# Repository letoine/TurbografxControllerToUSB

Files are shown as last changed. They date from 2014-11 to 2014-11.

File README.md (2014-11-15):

TurbografxControllerToUSB
=========================

Simple adapter that transforms a Turbografx controller into a USB controller.

Turbografx controller pinout
============================

pin |      name       | comment
----|-----------------|---------
 1  | +5V             |
 2  | Data0           |
 3  | Data1           |
 4  | Data2           |
 5  | Data3           |
 6  | Data select     |
 7  | ~Output Enable~ | Also used as clock for auto-fire
 8  | GND             |

Data select |   Data0    |   Data1   |     Data2     |    Data3
------------|------------|-----------|---------------|------------
 High       | Up         | Right     | Down          | Left
 Low        | I button   | II button | Select button | Run button
 High       | 0          | 0         | 0             | 0
 Low        | III button | IV button | V button      | VI button

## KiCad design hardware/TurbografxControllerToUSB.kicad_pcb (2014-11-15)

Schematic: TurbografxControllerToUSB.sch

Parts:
C1, C2: 22p
C3, C5: 100nf
C4: 1uf
CON1: AVR-ISP6; AVR-ISP-6
J1: USB
J2: DIN8
J3: MINIDIN8
R1, R2: 22ohms
R3: 10K
U1: ATMEGA32U2-AU
X1: 16Mhz

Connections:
DATA0: J2.2, J3.2, U1.9
DATA1: J2.3, J3.3, U1.7
DATA2: J2.4, J3.4, U1.10
DATA3: J2.5, J3.5, U1.8
DATA_SELECT: J2.6, J3.6, U1.11
GND: C1.2, C2.2, C3.1, C4.1, C5.2, CON1.6 (GND), J1.4 (GND), J1.5 (Shield_1), J1.6 (Shield_2), J2.8, J2.9 (shield), J3.8, J3.9 (shield), U1.3, U1.28
MISO: CON1.1 (MISO), U1.17
MOSI: CON1.4 (MOSI), U1.16
unnamed: R1.2, U1.30
unnamed: J1.2 (D-), R1.1
unnamed: J1.3 (D+), R2.1
unnamed: C4.2, U1.27
unnamed: R2.2, U1.29
unnamed: C2.1, U1.2, X1.2
unnamed: C1.1, U1.1, X1.1
RESET: C5.1, CON1.5 (RST), R3.2, U1.24
SCK: CON1.3 (SCK), U1.15
VCC: C3.2, CON1.2 (VCC), J1.1 (Vbus), J2.1, J3.1, R3.1, U1.4, U1.31, U1.32
~OE~: J2.7, J3.7, U1.6

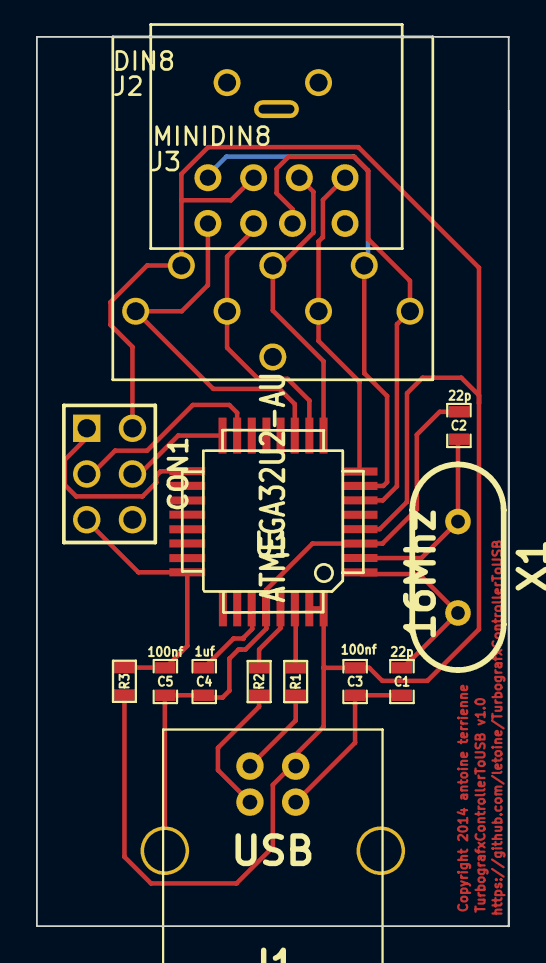
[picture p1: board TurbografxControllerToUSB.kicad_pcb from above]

Board: 2 copper layers, 26.2 x 49.4 mm, 14 parts (0 on the bottom side), 19 nets.

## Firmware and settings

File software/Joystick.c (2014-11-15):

#include "Joystick.h"

static uint8_t PrevJoystickHIDReportBuffer[sizeof(USB_JoystickReport_Data_t)];

/* TODO: Need to check at which frequency the console is toggling
         the chip_enable pin to reproduce the same autofire frequency.
static bool JoystickNeedsReset;

ISR(TIMER1_COMPA_vect) {
  JoystickNeedsReset = true;
}

void init_reset_timer() {
  JoystickNeedsReset = false;
  TCCR1A = 0;
  TCCR1B = _BV(WGM12);
  TCCR1C = 0;
  TCNT1 = 0;
  OCR1A = F_CPU/60;
  TIMSK1 |= _BV(OCIE1A); // enable timer interruption
  TCCR1B |= _BV(CS10); // enable timer clock
}
*/

USB_ClassInfo_HID_Device_t Joystick_HID_Interface = {
  .Config = {
    .InterfaceNumber = INTERFACE_ID_Joystick,
    .ReportINEndpoint = {
      .Address              = JOYSTICK_EPADDR,
      .Size                 = JOYSTICK_EPSIZE,
      .Banks                = 1,
    },
    .PrevReportINBuffer           = PrevJoystickHIDReportBuffer,
    .PrevReportINBufferSize       = sizeof(PrevJoystickHIDReportBuffer),
  },
};

#define IO_PIN	PIND
#define IO_PORT	PORTD
#define IO_DDR	DDRD

#define OUTPUT_ENABLE_PIN	0

#define DATA1_PIN		1
#define DATA3_PIN		2
#define DATA0_PIN		3
#define DATA2_PIN		4

#define SELECT_PIN		5

#define INPUT_PINS_MASK	(_BV(DATA0_PIN)|_BV(DATA1_PIN)|_BV(DATA2_PIN)|_BV(DATA3_PIN))
#define OUTPUT_PINS_MASK	(_BV(OUTPUT_ENABLE_PIN)|_BV(SELECT_PIN))

#define enable_controller_chip()	(IO_PORT &= ~(_BV(OUTPUT_ENABLE_PIN)))
#define disable_controller_chip()	(IO_PORT |= _BV(OUTPUT_ENABLE_PIN))
#define set_select_to_high()		(IO_PORT |= _BV(SELECT_PIN))
#define set_select_to_low()		(IO_PORT &= ~(_BV(SELECT_PIN)))

typedef union {
  uint8_t raw;
  struct {
    unsigned int pad1:1;
    
    unsigned int right:1;
    unsigned int left:1;
    unsigned int up:1;
    unsigned int down:1;
    
    unsigned int pad2:3;
  } directions;
  struct {
    unsigned int pad1:1;
    
    unsigned int II_btn:1;
    unsigned int run:1;
    unsigned int I_btn:1;
    unsigned int select:1;
    
    unsigned int pad2:3;
  } btn1;
  struct {
    unsigned int pad1:1;
    
    unsigned int IV_btn:1;
    unsigned int VI_btn:1;
    unsigned int III_btn:1;
    unsigned int V_btn:1;
    
    unsigned int pad2:3;
  } btn2;
} input_defs;

int main(void) {
  SetupHardware();
  
  GlobalInterruptEnable();
  
  set_select_to_high();
  for (;;) {
    HID_Device_USBTask(&Joystick_HID_Interface);
    USB_USBTask();
  }
}

void SetupHardware(void) {
  /* Disable watchdog if enabled by bootloader/fuses */
  MCUSR &= ~(1 << WDRF);
  wdt_disable();
  
  /* Disable clock division */
  clock_prescale_set(clock_div_1);
  
  /* Hardware Initialization */
  /* Set outputs to 1, other to 0 */
  IO_DDR = OUTPUT_PINS_MASK;
  
  /* Set pullup resistors on input pins */
  IO_PORT = (IO_PORT|INPUT_PINS_MASK);
  
  SerialDebug_init();
  USB_Init();
  //init_reset_timer();
}

void EVENT_USB_Device_ConfigurationChanged(void) {
  bool ConfigSuccess = true;
  
  SerialDebug_printf("EVENT_USB_Device_ConfigurationChanged\r\n");
  ConfigSuccess &= HID_Device_ConfigureEndpoints(&Joystick_HID_Interface);
  
  USB_Device_EnableSOFEvents();
}

void EVENT_USB_Device_ControlRequest(void) {
  SerialDebug_printf("EVENT_USB_Device_ControlRequest\r\n");
  HID_Device_ProcessControlRequest(&Joystick_HID_Interface);
}

void EVENT_USB_Device_StartOfFrame(void) {
  //SerialDebug_printf("EVENT_USB_Device_StartOfFrame\r\n");
  HID_Device_MillisecondElapsed(&Joystick_HID_Interface);
}

/* if all directions are pressed (0), it is not a direction information */
inline bool is_direction(input_defs inputs) {
  return (inputs.directions.up|
	  inputs.directions.down|
	  inputs.directions.left|
	  inputs.directions.right);
}

inline void SetDirections(USB_JoystickReport_Data_t* JoystickReport, input_defs inputs) {
    if (!inputs.directions.up)
    JoystickReport->Y = -127;
  else if (!inputs.directions.down)
    JoystickReport->Y =  127;
  
  if (!inputs.directions.left)
    JoystickReport->X = -127;
  else if (!inputs.directions.right)
    JoystickReport->X =  127;
}

inline void SetButtons1(USB_JoystickReport_Data_t* JoystickReport, input_defs inputs) {
  if (!inputs.btn1.I_btn)
    JoystickReport->button.square = 1;
  
  if (!inputs.btn1.II_btn)
    JoystickReport->button.cross = 1;
  
  if (!inputs.btn1.select)
    JoystickReport->button.select = 1;
  
  if (!inputs.btn1.run)
    JoystickReport->button.start = 1;
}

inline void SetButtons2(USB_JoystickReport_Data_t* JoystickReport, input_defs inputs) {
  if (!inputs.btn2.III_btn)
    JoystickReport->button.circle = 1;
  
  if (!inputs.btn2.IV_btn)
    JoystickReport->button.triangle = 1;
  
  if (!inputs.btn2.V_btn)
    JoystickReport->button.l1 = 1;
  
  if (!inputs.btn2.VI_btn)
    JoystickReport->button.r1 = 1;
}

inline void ReadController(USB_JoystickReport_Data_t* JoystickReport) {
  input_defs inputs;
  inputs.raw = IO_PIN;
  set_select_to_low();
  if (is_direction(inputs)) {
    SetDirections(JoystickReport, inputs);
    inputs.raw = IO_PIN;
    set_select_to_high();
    SetButtons1(JoystickReport, inputs);
  } else {
    inputs.raw = IO_PIN;
    set_select_to_high();
    SetButtons2(JoystickReport, inputs);
  }
}

inline void UpdateControllerStatus(USB_JoystickReport_Data_t* JoystickReport) {
  enable_controller_chip();
  set_select_to_high();
  
  JoystickReport->Y = 0;
  JoystickReport->X = 0;
  JoystickReport->button.raw[0] = 0;
  JoystickReport->button.raw[1] = 0;
  
  ReadController(JoystickReport);
  ReadController(JoystickReport);
  
  /*if (JoystickNeedsReset) {
    JoystickNeedsReset = false;
    disable_controller_chip();
    }*/
  disable_controller_chip();
}

bool CALLBACK_HID_Device_CreateHIDReport(USB_ClassInfo_HID_Device_t* const HIDInterfaceInfo,
                                         uint8_t* const ReportID,
                                         const uint8_t ReportType,
                                         void* ReportData,
                                         uint16_t* const ReportSize)
{
  USB_JoystickReport_Data_t* JoystickReport = (USB_JoystickReport_Data_t*)ReportData;
  UpdateControllerStatus(JoystickReport);
  *ReportSize = sizeof(USB_JoystickReport_Data_t);
  return false;
}

void CALLBACK_HID_Device_ProcessHIDReport(USB_ClassInfo_HID_Device_t* const HIDInterfaceInfo,
                                          const uint8_t ReportID,
                                          const uint8_t ReportType,
                                          const void* ReportData,
                                          const uint16_t ReportSize)
{
  SerialDebug_printf("CALLBACK_HID_Device_ProcessHIDReport\r\n");
  SerialDebug_printf("%#0x, %#0x\r\n", ReportID, ReportType);
  SerialDebug_printByteArray(ReportData, ReportSize);
  
  // Unused (but mandatory for the HID class driver) in this demo, since there are no Host->Device reports
}

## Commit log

2014-08-04 Adding sources. Simple copy of the MegadriveControllerToUSB project with renaming. Need to make scheatics and footprint for DIN8 connector.
    [TurbografxControllerToUSB.kicad_pcb, TurbografxControllerToUSB.sch]
2014-08-05 Adding DIN8 component.
    [TurbografxControllerToUSB.kicad_pcb, TurbografxControllerToUSB.sch]
2014-11-08 Adding code for firmware. Working with teensy, need to rework hardware part.
    [TurbografxControllerToUSB.kicad_pcb, TurbografxControllerToUSB.sch]
2014-11-09 Adding code to handle six buttons pads. Need to be tested with a 6 btn pad. Need to check the ebable/disable frequancy of the console to reproduce the same rate, and same autofire frequency.
2014-11-15 Slim down the board. Add footprind for mini-din8 on top of din8, this will allow to populate with both. Removing some kicad temp files.
    [TurbografxControllerToUSB.kicad_pcb, TurbografxControllerToUSB.sch]

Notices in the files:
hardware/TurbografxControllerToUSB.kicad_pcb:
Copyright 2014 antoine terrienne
